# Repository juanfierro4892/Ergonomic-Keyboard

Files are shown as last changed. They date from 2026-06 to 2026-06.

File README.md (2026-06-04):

The Ergonomic Keyboard

An split keyboard that helps you to maintain a good position while you work, play or whatever you do in a computer.

I designed this because I was tired of the back pains so I decided to design and build a keyboard that helps me to maintain a good postion.

Case:


It is designed in Fusion 360 made to fit and protect the PCB and all of the components that conforms it
The PCB here is how it end look like designed in KiCad with a lot of patience




The schematics that shows the connection between the XIAO and the capacitors and the switches




And finally the BOM which show what are the components that I'll be using 

[The Ergonomic Keyboard-bom .xlsx](https://github.com/user-attachments/files/28578072/The.Ergonomic.Keyboard-bom.xlsx)

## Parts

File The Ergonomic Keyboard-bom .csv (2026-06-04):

Name | Purpose | Quantity | Total Cost (USD) | Link | Distributor
Keycaps | Are the identifiers of the letters, the protector of the mechanism and they came 104 as the full keyboard keycap and they're green! | 104 | 7.51 | https://es.aliexpress.com/item/1005005259313543.html?pdp_ext_f=%7B"order"%3A"587"%2C"spu_best_type"%3A"price"%2C"eval"%3A"1"%2C"fromPage"%3A"search"%7D&pdp_npi=6%40dis%21USD%217.74%217.51%21%21%217.74%217.51%21%40210328c017805390703582664eb6bc%2112000032393281286%21sea%21CO%217499892959%21X%211%210%21n_tag%3A-29912%3Bd%3A891087ae%3Bm03_new_user%3A-29895&curPageLogUid=y6zYdip12BGX&utparam-url=scene%3Asearch%7Cquery_from%3A%7Cx_object_id%3A1005005259313543%7C_p_origin_prod%3A | Aliexpress
Microcontoller | To control what happens when a switch it's pressed | 2 | 21.56 | https://es.aliexpress.com/item/1005006988954136.html?pdp_ext_f=%7B"order"%3A"1935"%2C"eval"%3A"1"%2C"fromPage"%3A"search"%7D&pdp_npi=6%40dis%21USD%2118.59%2110.78%21%21%21125.54%2172.81%21%4021030a4b17798475046056962e4dc3%2112000042942288177%21sea%21CO%210%21ABX%211%210%21n_tag%3A-29910%3Bd%3A891087ae%3Bm03_new_user%3A-29895&curPageLogUid=JEf6rNpgm6uj&utparam-url=scene%3Asearch%7Cquery_from%3A%7Cx_object_id%3A1005006988954136%7C_p_origin_prod%3A | Aliexpress
Switches | Are the buttons of the keyboard, I selected 50 because there isn't less than I need | 42 | 25.86 | https://es.aliexpress.com/item/1005007917912136.html?pdp_ext_f=%7B"order"%3A"119"%2C"eval"%3A"1"%2C"fromPage"%3A"search"%7D&pdp_npi=6%40dis%21USD%218.75%217.94%21%21%2159.08%2153.60%21%4021033d1217798471947442073e1d27%2112000042837566043%21sea%21CO%210%21ABX%211%210%21n_tag%3A-29910%3Bd%3A891087ae%3Bm03_new_user%3A-29895&curPageLogUid=73QWeeDTUJMl&utparam-url=scene%3Asearch%7Cquery_from%3A%7Cx_object_id%3A1005007917912136%7C_p_origin_prod%3A | Aliexpress
PCB | To connect all the switches ant the microcontroller | 5 | 35.86 | https://cart.jlcpcb.com/quote?stencilLayer=2&stencilWidth=100&stencilLength=100&stencilCounts=5&plateType=1 | JLCPCB

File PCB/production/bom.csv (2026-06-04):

Designator | Footprint | Quantity | Value | LCSC Part #
D1, D10, D11, D12, D13, D14, D15, D16, D17, D18, D19, D2, D20, D21, D22, D23, D24, D25, D26, D27, D28, D29, D3, D30, D31, D32, D33, D34, D35, D36, D37, D38, D39, D4, D40, D41, D42, D5, D6, D7, D8, D9 | D_SOD-123 | 42 | D
R1, R2 | 0805 | 2 | 806k
R3, R4 | 0805 | 2 | 2M
SW1, SW10, SW11, SW12, SW13, SW14, SW15, SW16, SW17, SW18, SW19, SW2, SW20, SW21, SW22, SW23, SW24, SW25, SW26, SW27, SW28, SW29, SW3, SW30, SW31, SW32, SW33, SW34, SW35, SW36, SW37, SW38, SW39, SW4, SW40, SW41, SW42, SW5, SW6, SW7, SW8, SW9 | SW_Cherry_MX_1.00u_PCB | 42 | SW_Push
TP1, TP2 | TestPoint_Pad_D2.0mm | 2 | BAT
U3, U4 | modified-XIAO-nRF52840-SMD | 2 | XIAO-nRF52840-SMD

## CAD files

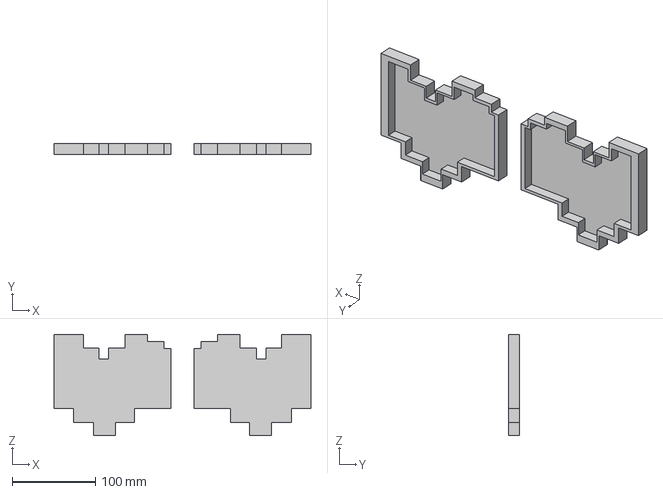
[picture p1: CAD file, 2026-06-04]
CAD/Split Keyboard Case 2.0.step
308.0 x 13.0 x 121.5 mm

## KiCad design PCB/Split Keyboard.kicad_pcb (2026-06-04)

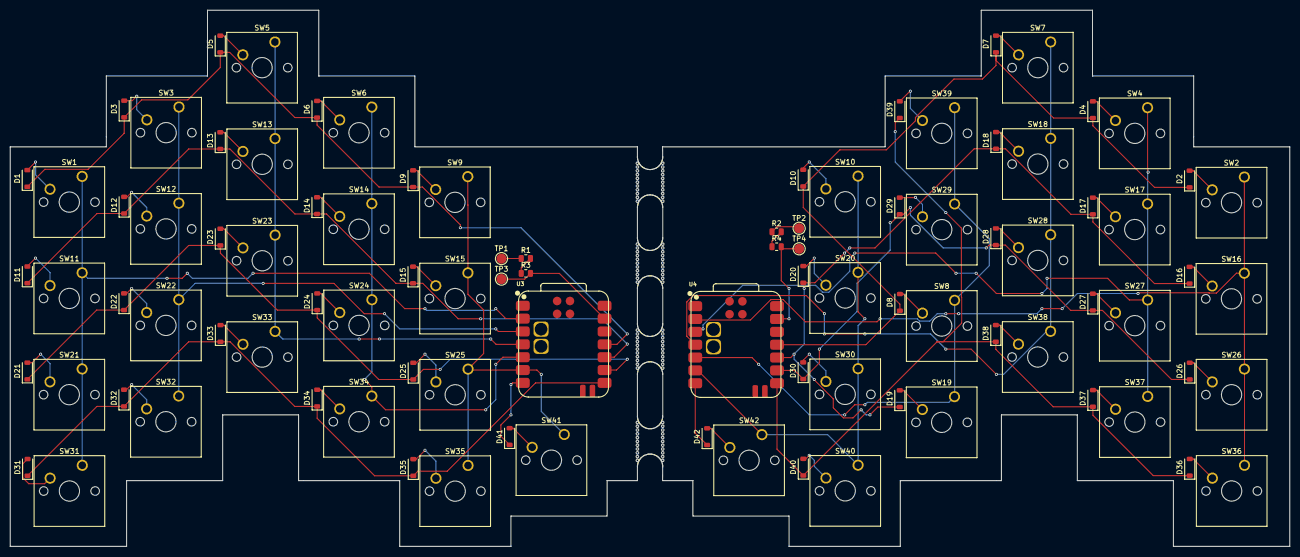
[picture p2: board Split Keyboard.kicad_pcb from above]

Board: 2 copper layers, 253.0 x 106.0 mm, 98 parts (0 on the bottom side), 67 nets.

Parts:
D1, D2, D3, D4, D5, D6, D7, D8, D9, D10, D11, D12, D13, D14, D15, D16, D17, D18, D19, D20, D21, D22, D23, D24, D25, D26, D27, D28, D29, D30, D31, D32, D33, D34, D35, D36, D37, D38, D39, D40, D41, D42: D; D_SOD-123
H7, H8, H9, H10: MountingHole; mouse-bite-5mm-slot (1)
R1, R2: 806k; R_0805_2012Metric
R3, R4: 2M; R_0805_2012Metric
SW1, SW2, SW3, SW4, SW5, SW6, SW7, SW8, SW9, SW10, SW11, SW12, SW13, SW14, SW15, SW16, SW17, SW18, SW19, SW20, SW21, SW22, SW23, SW24, SW25, SW26, SW27, SW28, SW29, SW30, SW31, SW32, SW33, SW34, SW35, SW36, SW37, SW38, SW39, SW40, SW41, SW42: SW_Push; SW_Cherry_MX_1.00u_PCB
TP1, TP2: BAT; TestPoint_Pad_D2.0mm
TP3, TP4: GND; TestPoint_Pad_D2.0mm
U3, U4: XIAO-nRF52840-SMD; modified-XIAO-nRF52840-SMD

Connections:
/left/BT_PIN: R1.2, R3.1
/left/COL0: SW1.1, SW11.1, SW21.1, SW31.1, U3.2 (P0.03_A1_D1)
/left/COL1: SW3.1, SW12.1, SW22.1, SW32.1, U3.3 (P0.28_A2_D2)
/left/COL2: SW5.1, SW13.1, SW23.1, SW33.1, U3.4 (P0.29_A3_D3)
/left/COL3: SW6.1, SW14.1, SW24.1, SW34.1, U3.5 (P0.04_A4_D4_SDA)
/left/COL4: SW9.1, SW15.1, SW25.1, SW35.1, SW41.1, U3.6 (P0.05_A5_D5_SCL)
/left/ROW0: D1.1 (K), D3.1 (K), D5.1 (K), D6.1 (K), D9.1 (K), U3.11 (P1.15_D10_MOSI)
/left/ROW1: D11.1 (K), D12.1 (K), D13.1 (K), D14.1 (K), D15.1 (K), U3.10 (P1.14_D9_MISO)
/left/ROW2: D21.1 (K), D22.1 (K), D23.1 (K), D24.1 (K), D25.1 (K), U3.9 (P1.13_D8_SCK)
/left/ROW3: D31.1 (K), D32.1 (K), D33.1 (K), D34.1 (K), D35.1 (K), U3.8 (P1.12_D7_RX)
/left/ROW4: D41.1 (K), U3.7 (P1.11_D6_TX)
/left/VBAT: R1.1, TP1.1 (1_1)
/right/BT_PIN: R2.2, R4.1
/right/COL0: SW2.1, SW16.1, SW26.1, SW36.1, U4.2 (P0.03_A1_D1)
/right/COL1: SW4.1, SW17.1, SW27.1, SW37.1, U4.3 (P0.28_A2_D2)
/right/COL2: SW7.1, SW18.1, SW28.1, SW38.1, U4.4 (P0.29_A3_D3)
/right/COL3: SW8.1, SW19.1, SW29.1, SW39.1, U4.5 (P0.04_A4_D4_SDA)
/right/COL4: SW10.1, SW20.1, SW30.1, SW40.1, SW42.1, U4.6 (P0.05_A5_D5_SCL)
/right/ROW0: D2.1 (K), D4.1 (K), D7.1 (K), D8.1 (K), D10.1 (K), U4.11 (P1.15_D10_MOSI)
/right/ROW1: D16.1 (K), D17.1 (K), D18.1 (K), D19.1 (K), D20.1 (K), U4.10 (P1.14_D9_MISO)
/right/ROW2: D26.1 (K), D27.1 (K), D28.1 (K), D29.1 (K), D30.1 (K), U4.9 (P1.13_D8_SCK)
/right/ROW3: D36.1 (K), D37.1 (K), D38.1 (K), D39.1 (K), D40.1 (K), U4.8 (P1.12_D7_RX)
/right/ROW4: D42.1 (K), U4.7 (P1.11_D6_TX)
/right/VBAT: R2.1, TP2.1 (1_1)
GND: R3.2, R4.2, TP3.1 (1_1), TP4.1 (1_1), U3.13 (GND), U4.13 (GND)
unnamed: D1.2 (A), SW1.2
unnamed: D2.2 (A), SW2.2
unnamed: D3.2 (A), SW3.2
unnamed: D4.2 (A), SW4.2
unnamed: D5.2 (A), SW5.2
unnamed: D6.2 (A), SW6.2
unnamed: D7.2 (A), SW7.2
unnamed: D8.2 (A), SW8.2
unnamed: D9.2 (A), SW9.2
unnamed: D10.2 (A), SW10.2
unnamed: D11.2 (A), SW11.2
unnamed: D12.2 (A), SW12.2
unnamed: D13.2 (A), SW13.2
unnamed: D14.2 (A), SW14.2
unnamed: D15.2 (A), SW15.2
unnamed: D16.2 (A), SW16.2
unnamed: D17.2 (A), SW17.2
unnamed: D18.2 (A), SW18.2
unnamed: D19.2 (A), SW19.2
unnamed: D20.2 (A), SW20.2
unnamed: D21.2 (A), SW21.2
unnamed: D22.2 (A), SW22.2
unnamed: D23.2 (A), SW23.2
unnamed: D24.2 (A), SW24.2
unnamed: D25.2 (A), SW25.2
unnamed: D26.2 (A), SW26.2
unnamed: D27.2 (A), SW27.2
unnamed: D28.2 (A), SW28.2
unnamed: D29.2 (A), SW29.2
unnamed: D30.2 (A), SW30.2
unnamed: D31.2 (A), SW31.2
unnamed: D32.2 (A), SW32.2
unnamed: D33.2 (A), SW33.2
unnamed: D34.2 (A), SW34.2
unnamed: D35.2 (A), SW35.2
unnamed: D36.2 (A), SW36.2
unnamed: D37.2 (A), SW37.2
unnamed: D38.2 (A), SW38.2
unnamed: D39.2 (A), SW39.2
unnamed: D40.2 (A), SW40.2
unnamed: D41.2 (A), SW41.2
unnamed: D42.2 (A), SW42.2

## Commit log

2026-06-04 Uploading all the flies to the REPO including the new designs of the PCB and CAD
    [Split Keyboard Case 2.0.step, Split Keyboard.kicad_pcb, Split Keyboard.kicad_sch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]
2026-06-04 Add README for Ergonomic Keyboard project
    Added detailed description and images of the ergonomic keyboard design, including case, PCB design, schematics, and BOM.
